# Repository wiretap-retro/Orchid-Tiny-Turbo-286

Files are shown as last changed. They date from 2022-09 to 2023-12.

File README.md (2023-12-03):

# Orchid Tiny Turbo 286
A clone of the Orchid Tiny Turbo 286 acclerator to upgrade an XT system. Based on schematics by Tube Time.

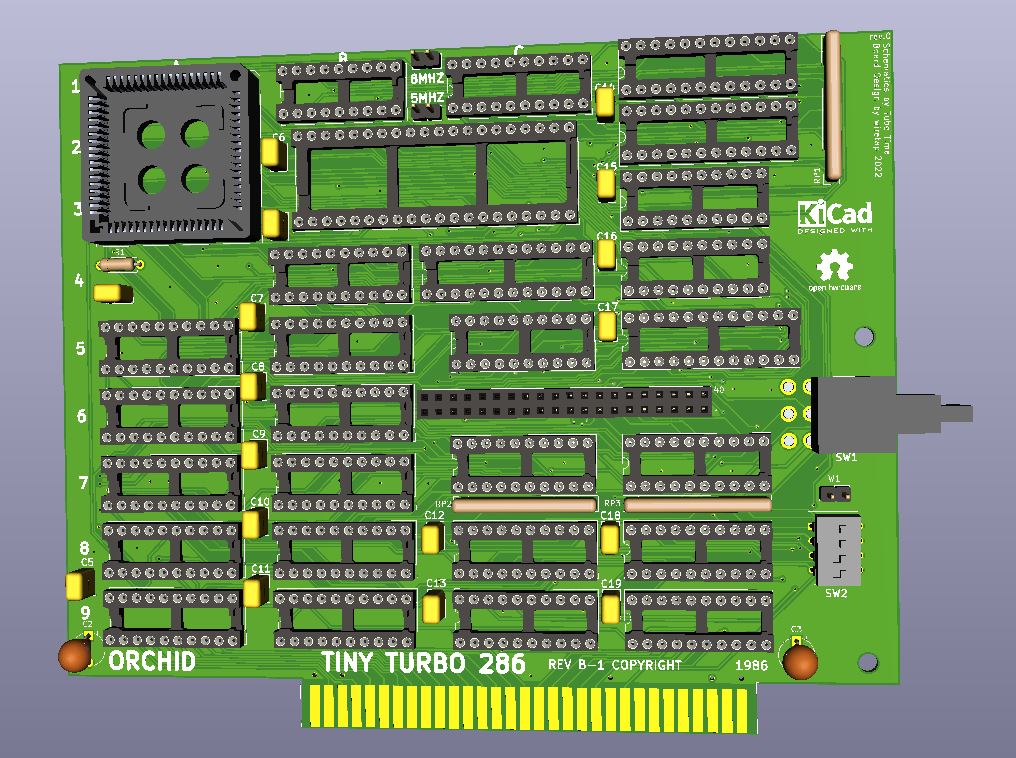
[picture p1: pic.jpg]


## Info / Warning
Build at your own risk This design is unconfirmed. PAL dumps have been added, courtesy of tomatolicious on the Retro Dreams and Techy Things Discord group. I do not have the original board, so this is a rough layout, not exactly the same size since it uses socketed footprints. However, it does abide by the ISA standard height (121.92mm) and uses a readily available slot cover that would need to be drilled for the switch to fit through. Board may require some more work -- this is considered a non-functional alpha release.
\
\
Built per the schematics from Tube Time's github found here: https://github.com/schlae/tiny-turbo-286

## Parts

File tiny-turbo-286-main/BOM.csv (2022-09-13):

Reference | Quantity | Value | Footprint | Datasheet
C1 | 1 | 0.1? | SamacSys_Parts:C320C104J3G5TA | ~
C3 C2 | 2 | 33uF 10V Tant | Capacitor_THT:CP_Radial_Tantal_D6.0mm_P5.00mm | ~
C4 C6 C8 C10 C12 C14 C16 C18 C5 C7 C9 C11 C13 C15 C17 C19 | 16 | 0.1uF | SamacSys_Parts:C320C104J3G5TA | ~
J1 | 1 | 8088_Max_Mode | Connector_PinSocket_2.54mm:PinSocket_2x20_P2.54mm_Vertical | http://datasheets.chipdb.org/Intel/x86/808x/datashts/8088/231456-006.pdf
J2 | 1 | Bus_ISA_8bit | SamacSys_Parts:BUS_XT | https://en.wikipedia.org/wiki/Industry_Standard_Architecture
R1 | 1 | 910 | Resistor_THT:R_Axial_DIN0207_L6.3mm_D2.5mm_P7.62mm_Horizontal | ~
RP2 RP3 RP1 | 3 | 4.7K | Resistor_THT:R_Array_SIP10 | http://www.vishay.com/docs/31509/csc.pdf
SW1 | 1 | TURBO | SamacSys_Parts:A201MD9AQ04
SW2 | 1 | SW_DIP_x04 | SamacSys_Parts:DIP810W60P254L1209H480Q8N | ~
UA2 | 1 | 80286_PLCC | Package_LCC:PLCC-68_THT-Socket
UA5 UA6 UB5 UB6 UB7 UB8 | 6 | IMS1423 | Package_DIP:DIP-20_W7.62mm_Socket
UA8 UA7 UD7 UD4 | 4 | 74ALS373 | Package_DIP:DIP-20_W7.62mm_Socket | http://www.ti.com/lit/gpn/sn74LS373
UA9 | 1 | 74LS541 | Package_DIP:DIP-20_W7.62mm_Socket | http://www.ti.com/lit/gpn/sn74LS541
UB1 | 1 | SAB82284 | Package_DIP:DIP-18_W7.62mm_Socket
UB2 | 1 | 80287 | Package_DIP:DIP-40_W15.24mm_Socket
UB4 | 1 | 74LS245 | Package_DIP:DIP-20_W7.62mm_Socket | http://www.ti.com/lit/gpn/sn74LS245
UB9 UC7 UC8 UD9 | 4 | 74ALS541 | Package_DIP:DIP-20_W7.62mm_Socket | http://www.ti.com/lit/gpn/sn74LS541
UC1 | 1 | 74AS804 | Package_DIP:DIP-20_W7.62mm_Socket
UC4 | 1 | 74LS646 | Package_DIP:DIP-24_W7.62mm_Socket
UC5 UD8 | 2 | PAL16L8 | Package_DIP:DIP-20_W7.62mm_Socket
UC9 | 1 | 74F521 | Package_DIP:DIP-20_W7.62mm_Socket | http://www.ti.com/lit/gpn/sn74LS688
UD1 | 1 | PAL20R6 | Package_DIP:DIP-24_W7.62mm_Socket
UD3 | 1 | PAL16R8 | Package_DIP:DIP-20_W7.62mm_Socket
UD5 UD2 | 2 | PAL20R4 | Package_DIP:DIP-24_W7.62mm_Socket
W1 | 1 | Jumper | Connector_PinHeader_2.54mm:PinHeader_1x02_P2.54mm_Vertical | ~
W2 | 1 | 8MHZ | Connector_PinHeader_2.54mm:PinHeader_1x02_P2.54mm_Vertical | ~
W3 | 1 | 5MHZ | Connector_PinHeader_2.54mm:PinHeader_1x02_P2.54mm_Vertical | ~

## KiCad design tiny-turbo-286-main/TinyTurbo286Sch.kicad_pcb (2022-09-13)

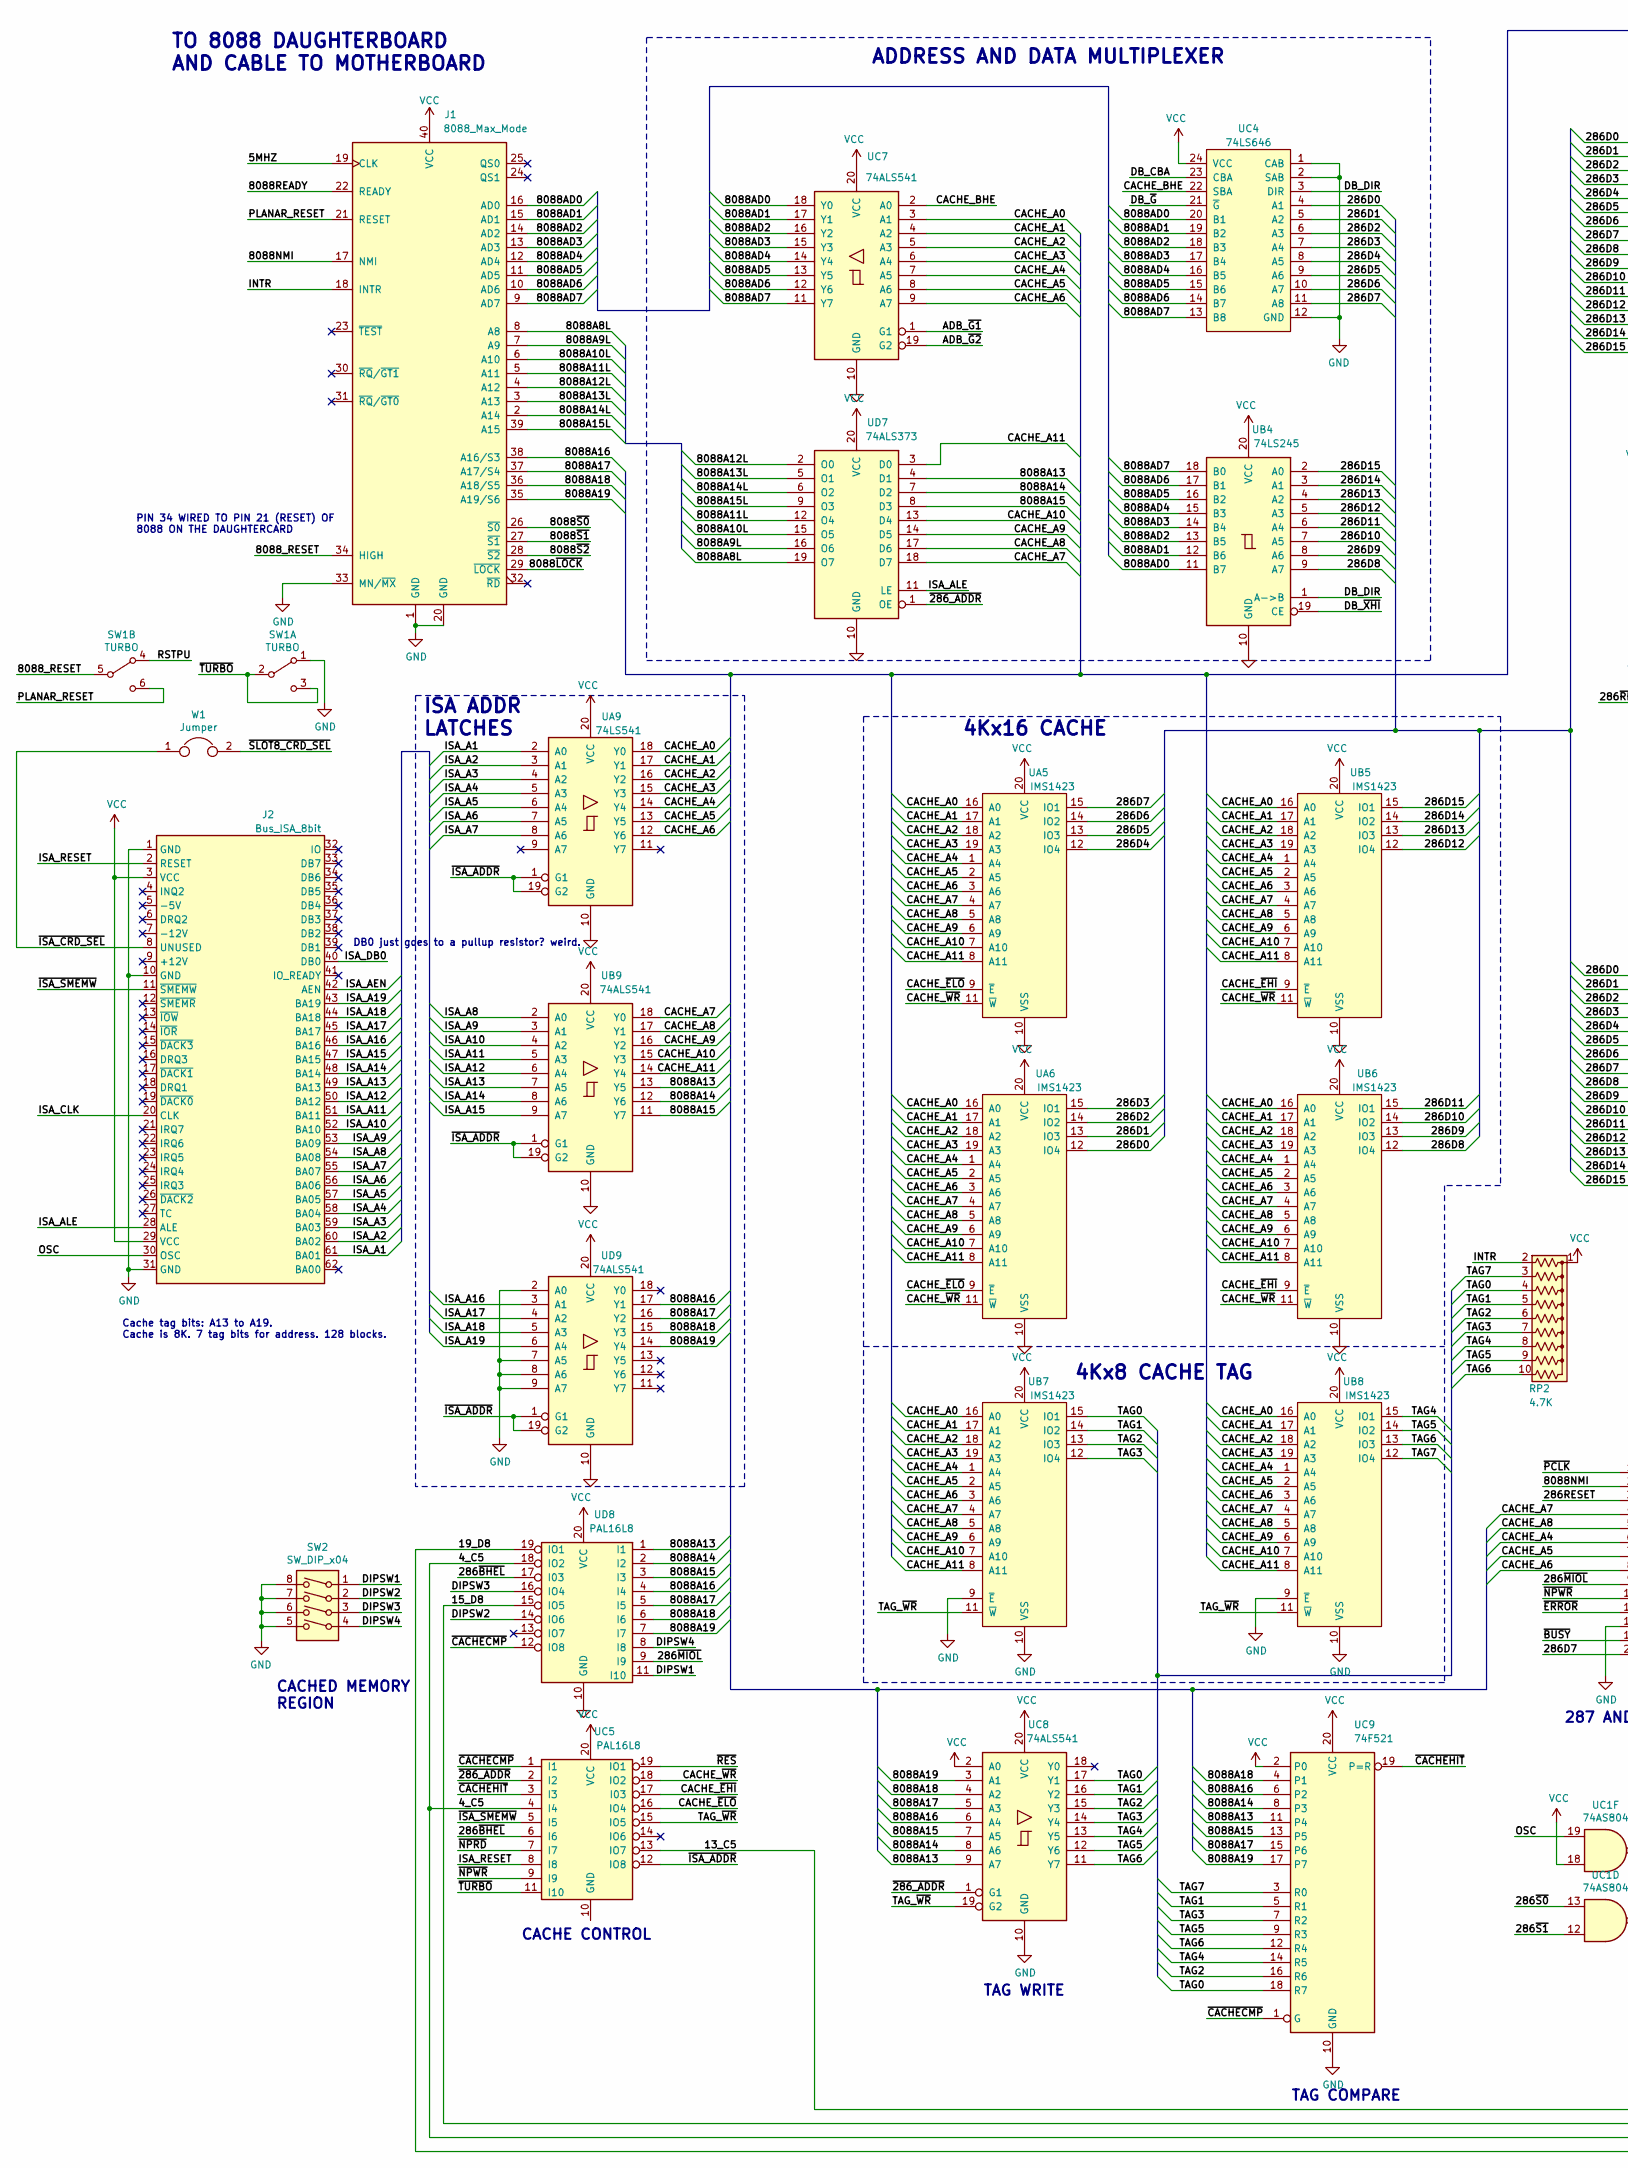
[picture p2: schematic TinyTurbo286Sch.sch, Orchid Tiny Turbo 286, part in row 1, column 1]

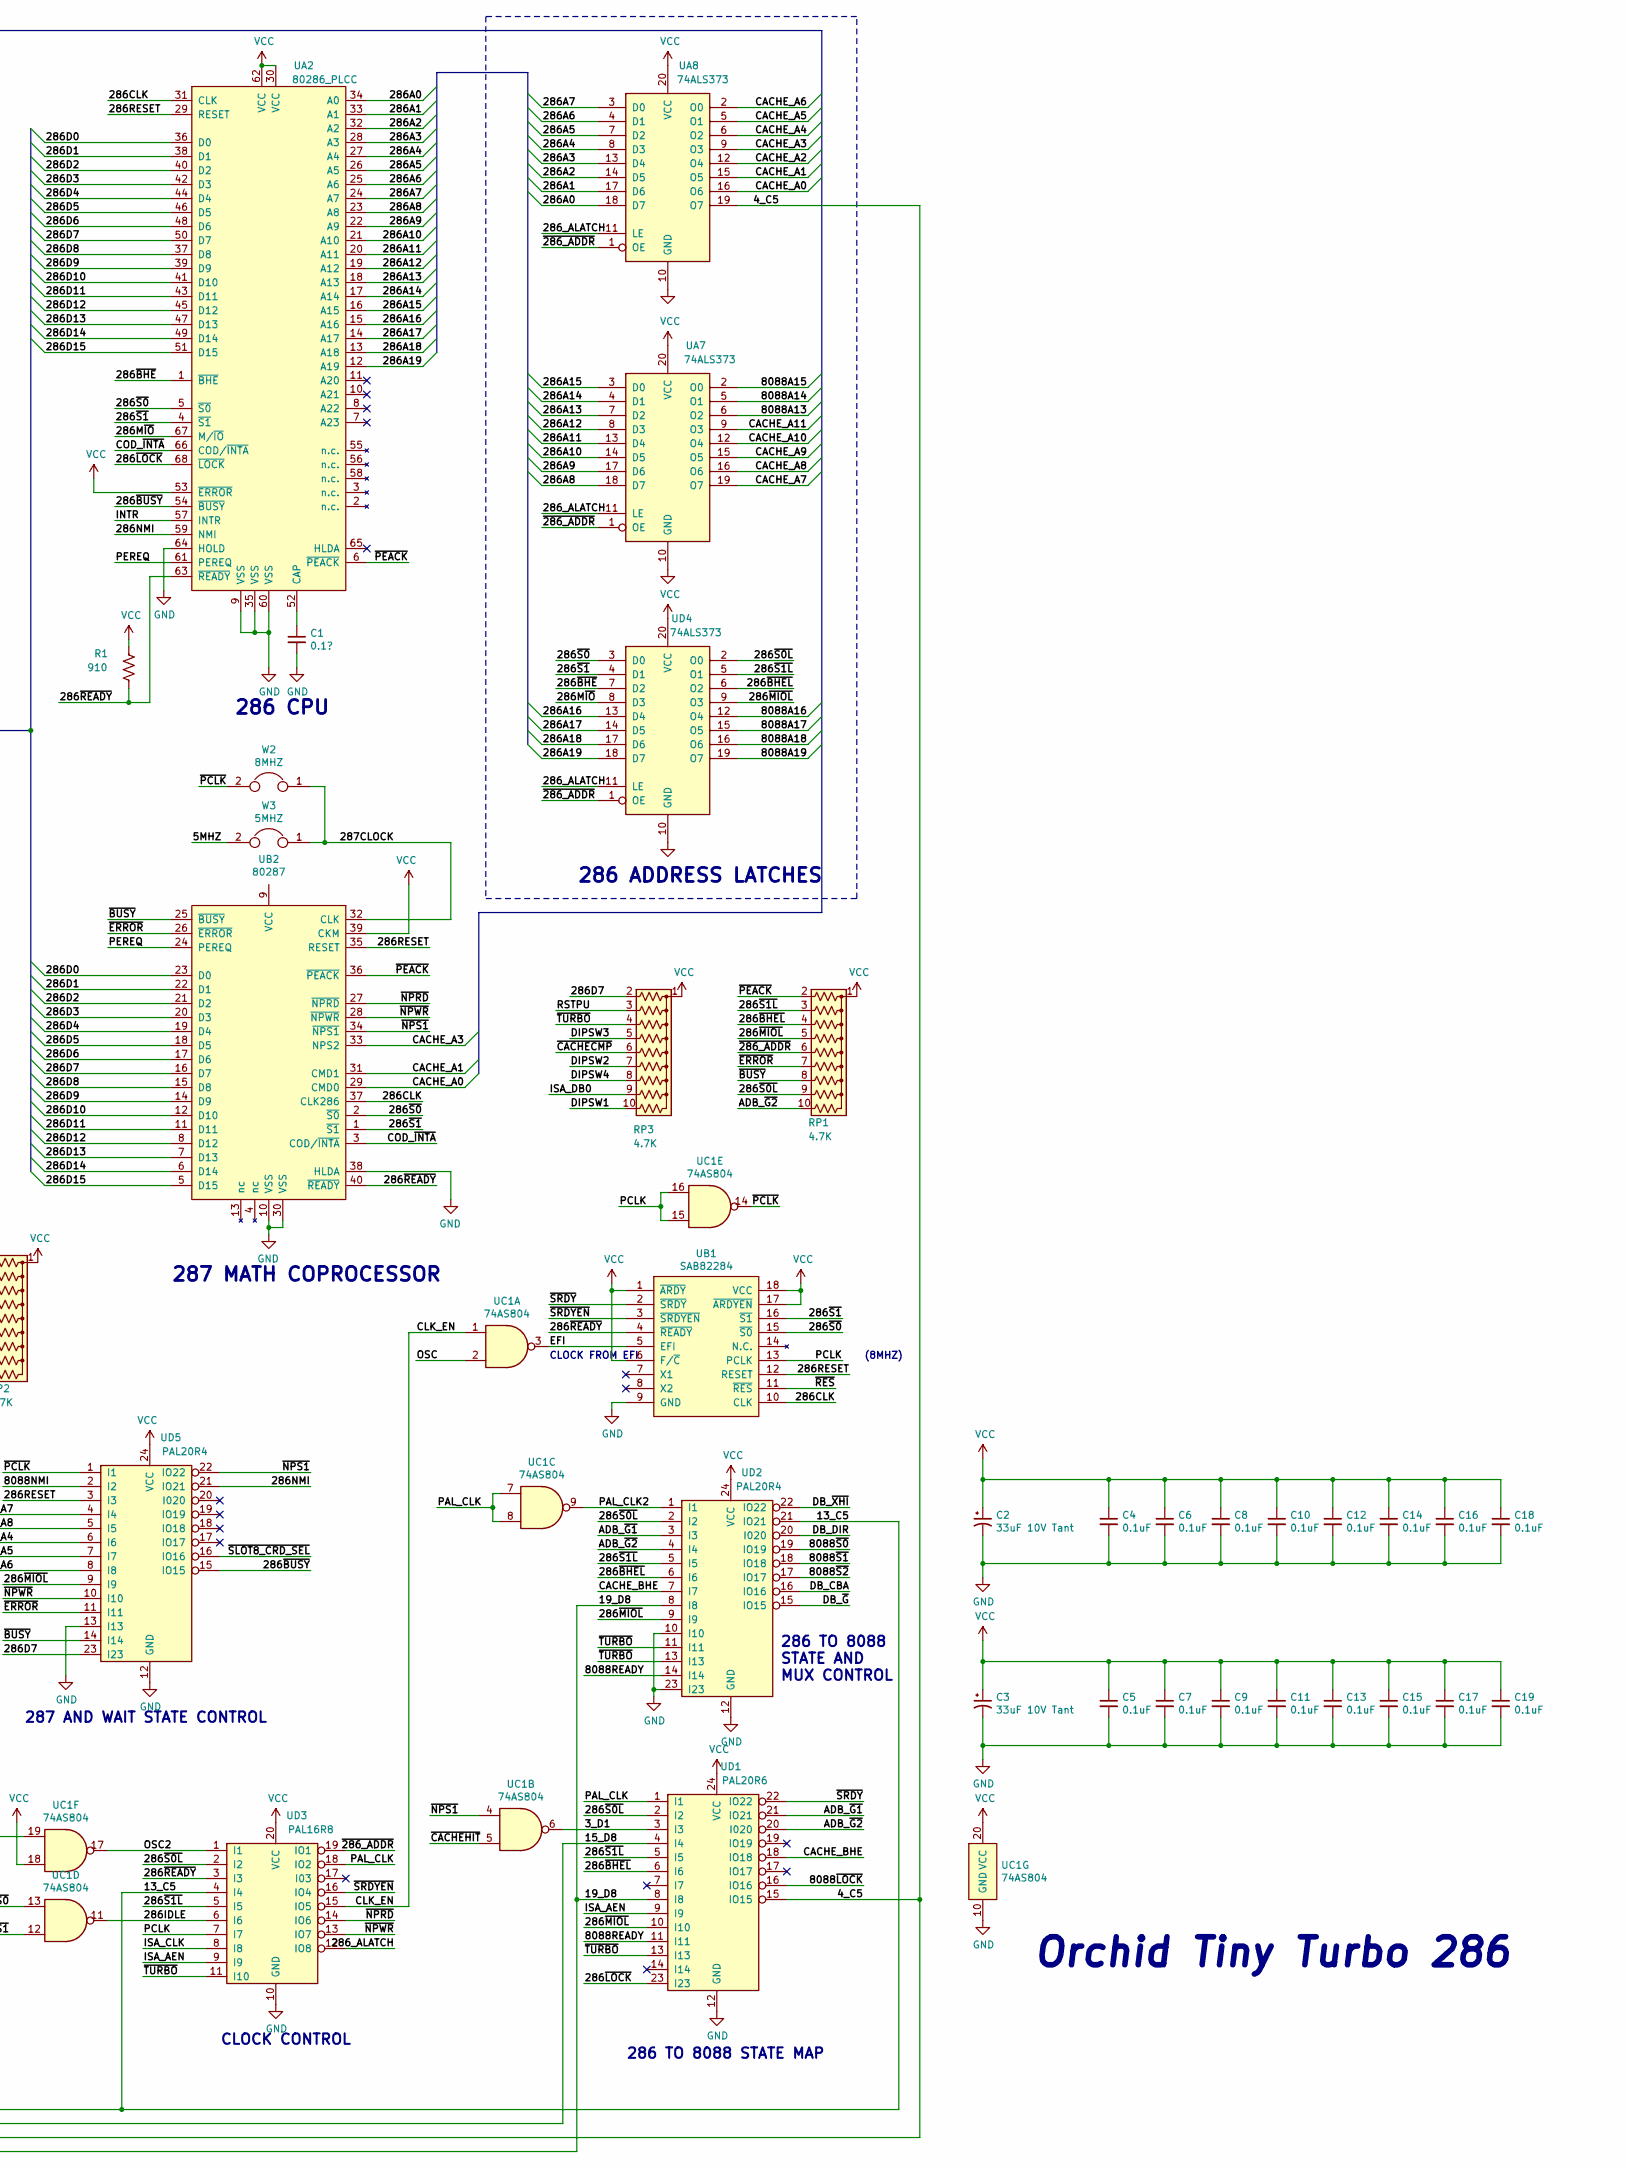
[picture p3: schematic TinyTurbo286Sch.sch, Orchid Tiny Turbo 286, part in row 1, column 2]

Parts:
C1: 0.1?; C320C104J3G5TA
C2, C3: 33uF 10V Tant; CP_Radial_Tantal_D6.0mm_P5.00mm
C4, C5, C6, C7, C8, C9, C10, C11, C12, C13, C14, C15, C16, C17, C18, C19: 0.1uF; C320C104J3G5TA
J1: 8088_Max_Mode; PinSocket_2x20_P2.54mm_Vertical
J2: Bus_ISA_8bit; BUS_XT
R1: 910; R_Axial_DIN0207_L6.3mm_D2.5mm_P7.62mm_Horizontal
RP1, RP2, RP3: 4.7K; R_Array_SIP10
SW1: TURBO; A201MD9AQ04
SW2: SW_DIP_x04; DIP810W60P254L1209H480Q8N
UA2: 80286_PLCC; PLCC-68_THT-Socket
UA5, UA6: IMS1423; DIP-20_W7.62mm_Socket
UA7, UA8: 74ALS373; DIP-20_W7.62mm_Socket
UA9: 74LS541; DIP-20_W7.62mm_Socket
UB1: SAB82284; DIP-18_W7.62mm_Socket
UB2: 80287; DIP-40_W15.24mm_Socket
UB4: 74LS245; DIP-20_W7.62mm_Socket
UB5, UB6, UB7, UB8: IMS1423; DIP-20_W7.62mm_Socket
UB9: 74ALS541; DIP-20_W7.62mm_Socket
UC1: 74AS804; DIP-20_W7.62mm_Socket
UC4: 74LS646; DIP-24_W7.62mm_Socket
UC5: PAL16L8; DIP-20_W7.62mm_Socket
UC7, UC8: 74ALS541; DIP-20_W7.62mm_Socket
UC9: 74F521; DIP-20_W7.62mm_Socket
UD1: PAL20R6; DIP-24_W7.62mm_Socket
UD2, UD5: PAL20R4; DIP-24_W7.62mm_Socket
UD3: PAL16R8; DIP-20_W7.62mm_Socket
UD4, UD7: 74ALS373; DIP-20_W7.62mm_Socket
UD8: PAL16L8; DIP-20_W7.62mm_Socket
UD9: 74ALS541; DIP-20_W7.62mm_Socket
W1: Jumper; PinHeader_1x02_P2.54mm_Vertical
W2: 8MHZ; PinHeader_1x02_P2.54mm_Vertical
W3: 5MHZ; PinHeader_1x02_P2.54mm_Vertical

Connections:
/3_D1: UC1.6, UD1.3 (I3)
/4_C5: UA8.19 (O7), UC5.4 (I4), UD1.15 (IO15), UD8.18 (IO2)
/5MHZ: J1.19 (CLK), W3.2
/13_C5: UC5.13 (IO7), UD2.21 (IO21), UD3.4 (I4)
/15_D8: UD1.4 (I4), UD8.15 (IO5)
/19_D8: UD1.8 (I8), UD2.8 (I8), UD8.19 (IO1)
/286A0: UA2.34 (A0), UA8.18 (D7)
/286A1: UA2.33 (A1), UA8.17 (D6)
/286A2: UA2.32 (A2), UA8.14 (D5)
/286A3: UA2.28 (A3), UA8.13 (D4)
/286A4: UA2.27 (A4), UA8.8 (D3)
/286A5: UA2.26 (A5), UA8.7 (D2)
/286A6: UA2.25 (A6), UA8.4 (D1)
/286A7: UA2.24 (A7), UA8.3 (D0)
/286A8: UA2.23 (A8), UA7.18 (D7)
/286A9: UA2.22 (A9), UA7.17 (D6)
/286A10: UA2.21 (A10), UA7.14 (D5)
/286A11: UA2.20 (A11), UA7.13 (D4)
/286A12: UA2.19 (A12), UA7.8 (D3)
/286A13: UA2.18 (A13), UA7.7 (D2)
/286A14: UA2.17 (A14), UA7.4 (D1)
/286A15: UA2.16 (A15), UA7.3 (D0)
/286A16: UA2.15 (A16), UD4.13 (D4)
/286A17: UA2.14 (A17), UD4.14 (D5)
/286A18: UA2.13 (A18), UD4.17 (D6)
/286A19: UA2.12 (A19), UD4.18 (D7)
/286CLK: UA2.31 (CLK), UB1.10 (CLK), UB2.37 (CLK286)
/286D0: UA2.36 (D0), UA6.12 (IO4), UB2.23 (D0), UC4.4 (A1)
/286D1: UA2.38 (D1), UA6.13 (IO3), UB2.22 (D1), UC4.5 (A2)
/286D2: UA2.40 (D2), UA6.14 (IO2), UB2.21 (D2), UC4.6 (A3)
/286D3: UA2.42 (D3), UA6.15 (IO1), UB2.20 (D3), UC4.7 (A4)
/286D4: UA2.44 (D4), UA5.12 (IO4), UB2.19 (D4), UC4.8 (A5)
/286D5: UA2.46 (D5), UA5.13 (IO3), UB2.18 (D5), UC4.9 (A6)
/286D6: UA2.48 (D6), UA5.14 (IO2), UB2.17 (D6), UC4.10 (A7)
/286D7: RP3.2 (R1), UA2.50 (D7), UA5.15 (IO1), UB2.16 (D7), UC4.11 (A8), UD5.23 (I23)
/286D8: UA2.37 (D8), UB2.15 (D8), UB4.9 (A7), UB6.12 (IO4)
/286D9: UA2.39 (D9), UB2.14 (D9), UB4.8 (A6), UB6.13 (IO3)
/286D10: UA2.41 (D10), UB2.12 (D10), UB4.7 (A5), UB6.14 (IO2)
/286D11: UA2.43 (D11), UB2.11 (D11), UB4.6 (A4), UB6.15 (IO1)
/286D12: UA2.45 (D12), UB2.8 (D12), UB4.5 (A3), UB5.12 (IO4)
/286D13: UA2.47 (D13), UB2.7 (D13), UB4.4 (A2), UB5.13 (IO3)
/286D14: UA2.49 (D14), UB2.6 (D14), UB4.3 (A1), UB5.14 (IO2)
/286D15: UA2.51 (D15), UB2.5 (D15), UB4.2 (A0), UB5.15 (IO1)
/286IDLE: UC1.11, UD3.6 (I6)
/286M~IO: UA2.67 (M/~IO), UD4.8 (D3)
/286NMI: UA2.59 (NMI), UD5.21 (IO21)
/286RESET: UA2.29 (RESET), UB1.12 (RESET), UB2.35 (RESET), UD5.3 (I3)
/286_ALATCH: UA7.11 (LE), UA8.11 (LE), UD3.12 (IO8), UD4.11 (LE)
/286~BHE: UA2.1 (~BHE), UD4.7 (D2)
/286~BHEL: RP1.4 (R3), UC5.6 (I6), UD1.6 (I6), UD2.6 (I6), UD4.6 (O2), UD8.17 (I03)
/286~BUSY: UA2.54 (~BUSY), UD5.15 (IO15)
/286~LOCK: UA2.68 (~LOCK), UD1.23 (I23)
/286~MIOL: RP1.5 (R4), UD1.10 (I10), UD2.9 (I9), UD4.9 (O3), UD5.9 (I9), UD8.9 (I9)
/286~READY: R1.2, UA2.63 (~READY), UB1.4 (~READY), UB2.40 (~READY), UD3.3 (I3)
/286~S0: UA2.5 (~S0), UB1.15 (~S0), UB2.2 (~S0), UC1.13, UD4.3 (D0)
/286~S0L: RP1.9 (R8), UD1.2 (I2), UD2.2 (I2), UD3.2 (I2), UD4.2 (O0)
/286~S1: UA2.4 (~S1), UB1.16 (~S1), UB2.1 (~S1), UC1.12, UD4.4 (D1)
/286~S1L: RP1.3 (R2), UD1.5 (I5), UD2.5 (I5), UD3.5 (I5), UD4.5 (O1)
/287CLOCK: UB2.32 (CLK), W2.1, W3.1
/8088A8L: J1.8 (A8), UD7.19 (O7)
/8088A9L: J1.7 (A9), UD7.16 (O6)
/8088A10L: J1.6 (A10), UD7.15 (O5)
/8088A11L: J1.5 (A11), UD7.12 (O4)
/8088A12L: J1.4 (A12), UD7.2 (O0)
/8088A13: UA7.6 (O2), UB9.13 (Y5), UC8.9 (A7), UC9.11 (P4), UD7.4 (D1), UD8.1 (I1)
/8088A13L: J1.3 (A13), UD7.5 (O1)
/8088A14: UA7.5 (O1), UB9.12 (Y6), UC8.8 (A6), UC9.8 (P3), UD7.7 (D2), UD8.2 (I2)
/8088A14L: J1.2 (A14), UD7.6 (O2)
/8088A15: UA7.2 (O0), UB9.11 (Y7), UC8.7 (A5), UC9.13 (P5), UD7.8 (D3), UD8.3 (I3)
/8088A15L: J1.39 (A15), UD7.9 (O3)
/8088A16: J1.38 (A16/S3), UC8.6 (A4), UC9.6 (P2), UD4.12 (O4), UD8.4 (I4), UD9.17 (Y1)
/8088A17: J1.37 (A17/S4), UC8.5 (A3), UC9.15 (P6), UD4.15 (O5), UD8.5 (I5), UD9.16 (Y2)
/8088A18: J1.36 (A18/S5), UC8.4 (A2), UC9.4 (P1), UD4.16 (O6), UD8.6 (I6), UD9.15 (Y3)
/8088A19: J1.35 (A19/S6), UC8.3 (A1), UC9.17 (P7), UD4.19 (O7), UD8.7 (I7), UD9.14 (Y4)
/8088AD0: J1.16 (AD0), UB4.11 (B7), UC4.20 (B1), UC7.18 (Y0)
/8088AD1: J1.15 (AD1), UB4.12 (B6), UC4.19 (B2), UC7.17 (Y1)
/8088AD2: J1.14 (AD2), UB4.13 (B5), UC4.18 (B3), UC7.16 (Y2)
/8088AD3: J1.13 (AD3), UB4.14 (B4), UC4.17 (B4), UC7.15 (Y3)
/8088AD4: J1.12 (AD4), UB4.15 (B3), UC4.16 (B5), UC7.14 (Y4)
/8088AD5: J1.11 (AD5), UB4.16 (B2), UC4.15 (B6), UC7.13 (Y5)
/8088AD6: J1.10 (AD6), UB4.17 (B1), UC4.14 (B7), UC7.12 (Y6)
/8088AD7: J1.9 (AD7), UB4.18 (B0), UC4.13 (B8), UC7.11 (Y7)
/8088NMI: J1.17 (NMI), UD5.2 (I2)
/8088READY: J1.22 (READY), UD1.11 (I11), UD2.14 (I14)
/8088_RESET: J1.34 (HIGH), SW1.5 (B)
/8088~LOCK: J1.29 (~LOCK~), UD1.16 (IO16)
/8088~S0: J1.26 (~S0~), UD2.19 (IO19)
/8088~S1: J1.27 (~S1~), UD2.18 (IO18)
/8088~S2: J1.28 (~S2~), UD2.17 (IO17)
/ADB_~G1: UC7.1 (G1), UD1.21 (IO21), UD2.3 (I3)
/ADB_~G2: RP1.10 (R9), UC7.19 (G2), UD1.20 (I020), UD2.4 (I4)
/CACHE_A0: UA5.16 (A0), UA6.16 (A0), UA8.16 (O6), UA9.18 (Y0), UB2.29 (CMD0), UB5.16 (A0), UB6.16 (A0), UB7.16 (A0), UB8.16 (A0), UC7.3 (A1)
/CACHE_A1: UA5.17 (A1), UA6.17 (A1), UA8.15 (O5), UA9.17 (Y1), UB2.31 (CMD1), UB5.17 (A1), UB6.17 (A1), UB7.17 (A1), UB8.17 (A1), UC7.4 (A2)
/CACHE_A2: UA5.18 (A2), UA6.18 (A2), UA8.12 (O4), UA9.16 (Y2), UB5.18 (A2), UB6.18 (A2), UB7.18 (A2), UB8.18 (A2), UC7.5 (A3)
/CACHE_A3: UA5.19 (A3), UA6.19 (A3), UA8.9 (O3), UA9.15 (Y3), UB2.33 (NPS2), UB5.19 (A3), UB6.19 (A3), UB7.19 (A3), UB8.19 (A3), UC7.6 (A4)
/CACHE_A4: UA5.1 (A4), UA6.1 (A4), UA8.6 (O2), UA9.14 (Y4), UB5.1 (A4), UB6.1 (A4), UB7.1 (A4), UB8.1 (A4), UC7.7 (A5), UD5.6 (I6)
/CACHE_A5: UA5.2 (A5), UA6.2 (A5), UA8.5 (O1), UA9.13 (Y5), UB5.2 (A5), UB6.2 (A5), UB7.2 (A5), UB8.2 (A5), UC7.8 (A6), UD5.7 (I7)
/CACHE_A6: UA5.3 (A6), UA6.3 (A6), UA8.2 (O0), UA9.12 (Y6), UB5.3 (A6), UB6.3 (A6), UB7.3 (A6), UB8.3 (A6), UC7.9 (A7), UD5.8 (I8)
/CACHE_A7: UA5.4 (A7), UA6.4 (A7), UA7.19 (O7), UB5.4 (A7), UB6.4 (A7), UB7.4 (A7), UB8.4 (A7), UB9.18 (Y0), UD5.4 (I4), UD7.18 (D7)
/CACHE_A8: UA5.5 (A8), UA6.5 (A8), UA7.16 (O6), UB5.5 (A8), UB6.5 (A8), UB7.5 (A8), UB8.5 (A8), UB9.17 (Y1), UD5.5 (I5), UD7.17 (D6)
/CACHE_A9: UA5.6 (A9), UA6.6 (A9), UA7.15 (O5), UB5.6 (A9), UB6.6 (A9), UB7.6 (A9), UB8.6 (A9), UB9.16 (Y2), UD7.14 (D5)
/CACHE_A10: UA5.7 (A10), UA6.7 (A10), UA7.12 (O4), UB5.7 (A10), UB6.7 (A10), UB7.7 (A10), UB8.7 (A10), UB9.15 (Y3), UD7.13 (D4)
/CACHE_A11: UA5.8 (A11), UA6.8 (A11), UA7.9 (O3), UB5.8 (A11), UB6.8 (A11), UB7.8 (A11), UB8.8 (A11), UB9.14 (Y4), UD7.3 (D0)
/CACHE_BHE: UC4.22 (SBA), UC7.2 (A0), UD1.18 (IO18), UD2.7 (I7)
/CACHE_~EHI: UB5.9 (~E), UB6.9 (~E), UC5.17 (I03)
/CACHE_~ELO: UA5.9 (~E), UA6.9 (~E), UC5.16 (IO4)
/CACHE_~WR: UA5.11 (~W), UA6.11 (~W), UB5.11 (~W), UB6.11 (~W), UC5.18 (IO2)
/CLK_EN: UC1.1, UD3.15 (IO5)
/COD_~INTA: UA2.66 (COD/~INTA), UB2.3 (COD/~INTA)
/DB_CBA: UC4.23 (CBA), UD2.16 (IO16)
/DB_DIR: UB4.1 (A->B), UC4.3 (DIR), UD2.20 (I020)
/DB_~G: UC4.21 (~G), UD2.15 (IO15)
/DB_~XHI: UB4.19 (CE), UD2.22 (IO22)
/DIPSW1: RP3.10 (R9), SW2.1, UD8.11 (I10)
/DIPSW2: RP3.7 (R6), SW2.2, UD8.14 (IO6)
/DIPSW3: RP3.5 (R4), SW2.3, UD8.16 (IO4)
/DIPSW4: RP3.8 (R7), SW2.4, UD8.8 (I8)
/EFI: UB1.5 (EFI), UC1.3
/INTR: J1.18 (INTR), RP2.2 (R1), UA2.57 (INTR)
/ISA_A1: J2.61 (BA01), UA9.2 (A0)
/ISA_A2: J2.60 (BA02), UA9.3 (A1)
/ISA_A3: J2.59 (BA03), UA9.4 (A2)
/ISA_A4: J2.58 (BA04), UA9.5 (A3)
/ISA_A5: J2.57 (BA05), UA9.6 (A4)
/ISA_A6: J2.56 (BA06), UA9.7 (A5)
/ISA_A7: J2.55 (BA07), UA9.8 (A6)
/ISA_A8: J2.54 (BA08), UB9.2 (A0)
/ISA_A9: J2.53 (BA09), UB9.3 (A1)
/ISA_A10: J2.52 (BA10), UB9.4 (A2)
/ISA_A11: J2.51 (BA11), UB9.5 (A3)
/ISA_A12: J2.50 (BA12), UB9.6 (A4)
/ISA_A13: J2.49 (BA13), UB9.7 (A5)
/ISA_A14: J2.48 (BA14), UB9.8 (A6)
/ISA_A15: J2.47 (BA15), UB9.9 (A7)
/ISA_A16: J2.46 (BA16), UD9.3 (A1)
/ISA_A17: J2.45 (BA17), UD9.4 (A2)
/ISA_A18: J2.44 (BA18), UD9.5 (A3)
/ISA_A19: J2.43 (BA19), UD9.6 (A4)
/ISA_AEN: J2.42 (AEN), UD1.9 (I9), UD3.9 (I9)
/ISA_ALE: J2.28 (ALE), UD7.11 (LE)
/ISA_CLK: J2.20 (CLK), UD3.8 (I8)
/ISA_DB0: J2.40 (DB0), RP3.9 (R8)
/ISA_RESET: J2.2 (RESET), UC5.8 (I8)
/OSC: J2.30 (OSC), UC1.2, UC1.19
/OSC2: UC1.17, UD3.1 (I1)
/PAL_CLK: UC1.7, UC1.8, UD1.1 (I1), UD3.18 (IO2)
/PAL_CLK2: UC1.9, UD2.1 (I1)
/PCLK: UB1.13 (PCLK), UC1.15, UC1.16, UD3.7 (I7)
/PEREQ: UA2.61 (PEREQ), UB2.24 (PEREQ)
/PLANAR_RESET: J1.21 (RESET), SW1.6 (C)
/RSTPU: RP3.3 (R2), SW1.4 (A)
/TAG0: RP2.4 (R3), UB7.15 (IO1), UC8.17 (Y1), UC9.18 (R7)
/TAG1: RP2.5 (R4), UB7.14 (IO2), UC8.16 (Y2), UC9.5 (R1)
/TAG2: RP2.6 (R5), UB7.13 (IO3), UC8.15 (Y3), UC9.16 (R6)
/TAG3: RP2.7 (R6), UB7.12 (IO4), UC8.14 (Y4), UC9.7 (R2)
/TAG4: RP2.8 (R7), UB8.15 (IO1), UC8.13 (Y5), UC9.14 (R5)
/TAG5: RP2.9 (R8), UB8.14 (IO2), UC8.12 (Y6), UC9.9 (R3)
/TAG6: RP2.10 (R9), UB8.13 (IO3), UC8.11 (Y7), UC9.12 (R4)
/TAG7: RP2.3 (R2), UB8.12 (IO4), UC9.3 (R0)
/TAG_~WR: UB7.11 (~W), UB8.11 (~W), UC5.15 (IO5), UC8.19 (G2)
/~286_ADDR: RP1.6 (R5), UA7.1 (OE), UA8.1 (OE), UC5.2 (I2), UC8.1 (G1), UD3.19 (IO1), UD4.1 (OE), UD7.1 (OE)
/~BUSY: RP1.8 (R7), UB2.25 (~BUSY), UD5.14 (I14)
/~CACHECMP: RP3.6 (R5), UC5.1 (I1), UC9.1 (G), UD8.12 (IO8)
/~CACHEHIT: UC1.5, UC5.3 (I3), UC9.19 (P=R)
/~ERROR: RP1.7 (R6), UB2.26 (~ERROR), UD5.11 (I11)
/~ISA_ADDR: UA9.1 (G1), UA9.19 (G2), UB9.1 (G1), UB9.19 (G2), UC5.12 (IO8), UD9.1 (G1), UD9.19 (G2)
/~ISA_CRD_SEL: J2.8 (UNUSED), W1.1
/~ISA_SMEMW: J2.11 (~SMEMW), UC5.5 (I5)
/~NPRD: UB2.27 (~NPRD), UC5.7 (I7), UD3.14 (IO6)
/~NPS1: UB2.34 (~NPS1), UC1.4, UD5.22 (IO22)
/~NPWR: UB2.28 (~NPWR), UC5.9 (I9), UD3.13 (IO7), UD5.10 (I10)
/~PCLK: UC1.14, UD5.1 (I1), W2.2
/~PEACK: RP1.2 (R1), UA2.6 (~PEACK), UB2.36 (~PEACK)
/~RES: UB1.11 (~RES), UC5.19 (IO1)
/~SLOT8_CRD_SEL: UD5.16 (IO16), W1.2
/~SRDY: UB1.2 (~SRDY), UD1.22 (IO22)
/~SRDYEN: UB1.3 (~SRDYEN), UD3.16 (IO4)
/~TURBO: RP3.4 (R3), SW1.2 (B), SW1.3 (C), UC5.11 (I10), UD1.13 (I13), UD2.11 (I11), UD2.13 (I13), UD3.11 (I10)
GND: C1.2, C2.2, C3.2, C4.2, C5.2, C6.2, C7.2, C8.2, C9.2, C10.2, C11.2, C12.2, C13.2, C14.2, C15.2, C16.2, C17.2, C18.2, C19.2, J1.1 (GND), J1.20 (GND), J1.33 (MN/~MX~), J2.1 (GND), J2.10 (GND), J2.31 (GND), SW1.1 (A), SW2.5, SW2.6, SW2.7, SW2.8, UA2.9 (VSS), UA2.35 (VSS), UA2.60 (VSS), UA2.64 (HOLD), UA5.10 (VSS), UA6.10 (VSS), UA7.10 (GND), UA8.10 (GND), UA9.10 (GND), UB1.9 (GND), UB2.10 (VSS), UB2.30 (VSS), UB2.38 (HLDA), UB4.10 (GND), UB5.10 (VSS), UB6.10 (VSS), UB7.9 (~E), UB7.10 (VSS), UB8.9 (~E), UB8.10 (VSS), UB9.10 (GND), UC1.10 (GND), UC4.1 (CAB), UC4.2 (SAB), UC4.12 (GND), UC7.10 (GND), UC8.10 (GND), UC9.10 (GND), UD1.12 (GND), UD2.10 (I10), UD2.12 (GND), UD2.23 (I23), UD3.10 (GND), UD4.10 (GND), UD5.12 (GND), UD5.13 (I13), UD7.10 (GND), UD8.10 (GND), UD9.2 (A0), UD9.7 (A5), UD9.8 (A6), UD9.9 (A7), UD9.10 (GND)
unnamed: C1.1, UA2.52 (CAP)
VCC: C2.1, C3.1, C4.1, C5.1, C6.1, C7.1, C8.1, C9.1, C10.1, C11.1, C12.1, C13.1, C14.1, C15.1, C16.1, C17.1, C18.1, C19.1, J1.40 (VCC), J2.3 (VCC), J2.29 (VCC), R1.1, RP1.1 (common), RP2.1 (common), RP3.1 (common), UA2.30 (VCC), UA2.53 (~ERROR), UA2.62 (VCC), UA5.20 (VCC), UA6.20 (VCC), UA7.20 (VCC), UA8.20 (VCC), UA9.20 (VCC), UB1.1 (~ARDY), UB1.6 (F/~C), UB1.17 (~ARDYEN), UB1.18 (VCC), UB2.39 (CKM), UB4.20 (VCC), UB5.20 (VCC), UB6.20 (VCC), UB7.20 (VCC), UB8.20 (VCC), UB9.20 (VCC), UC1.18, UC1.20 (VCC), UC4.24 (VCC), UC5.20 (VCC), UC7.20 (VCC), UC8.2 (A0), UC8.20 (VCC), UC9.2 (P0), UC9.20 (VCC), UD1.24 (VCC), UD2.24 (VCC), UD3.20 (VCC), UD4.20 (VCC), UD5.24 (VCC), UD7.20 (VCC), UD8.20 (VCC), UD9.20 (VCC)

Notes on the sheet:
Cache tag bits: A13 to A19. Cache is 8K. 7 tag bits for address. 128 blocks.
PIN 34 WIRED TO PIN 21 (RESET) OF 8088 ON THE DAUGHTERCARD
CLOCK FROM EFI
DB0 just goes to a pullup resistor? weird.
CACHE CONTROL
287 AND WAIT STATE CONTROL
CLOCK CONTROL
286 TO 8088 STATE AND MUX CONTROL
286 TO 8088 STATE MAP
CACHED MEMORY REGION
TAG WRITE
TAG COMPARE
287 MATH COPROCESSOR
286 CPU
286 ADDRESS LATCHES
(8MHZ)
4Kx8 CACHE TAG
4Kx16 CACHE
ADDRESS AND DATA MULTIPLEXER
ISA ADDR LATCHES
TO 8088 DAUGHTERBOARD AND CABLE TO MOTHERBOARD
Orchid Tiny Turbo 286

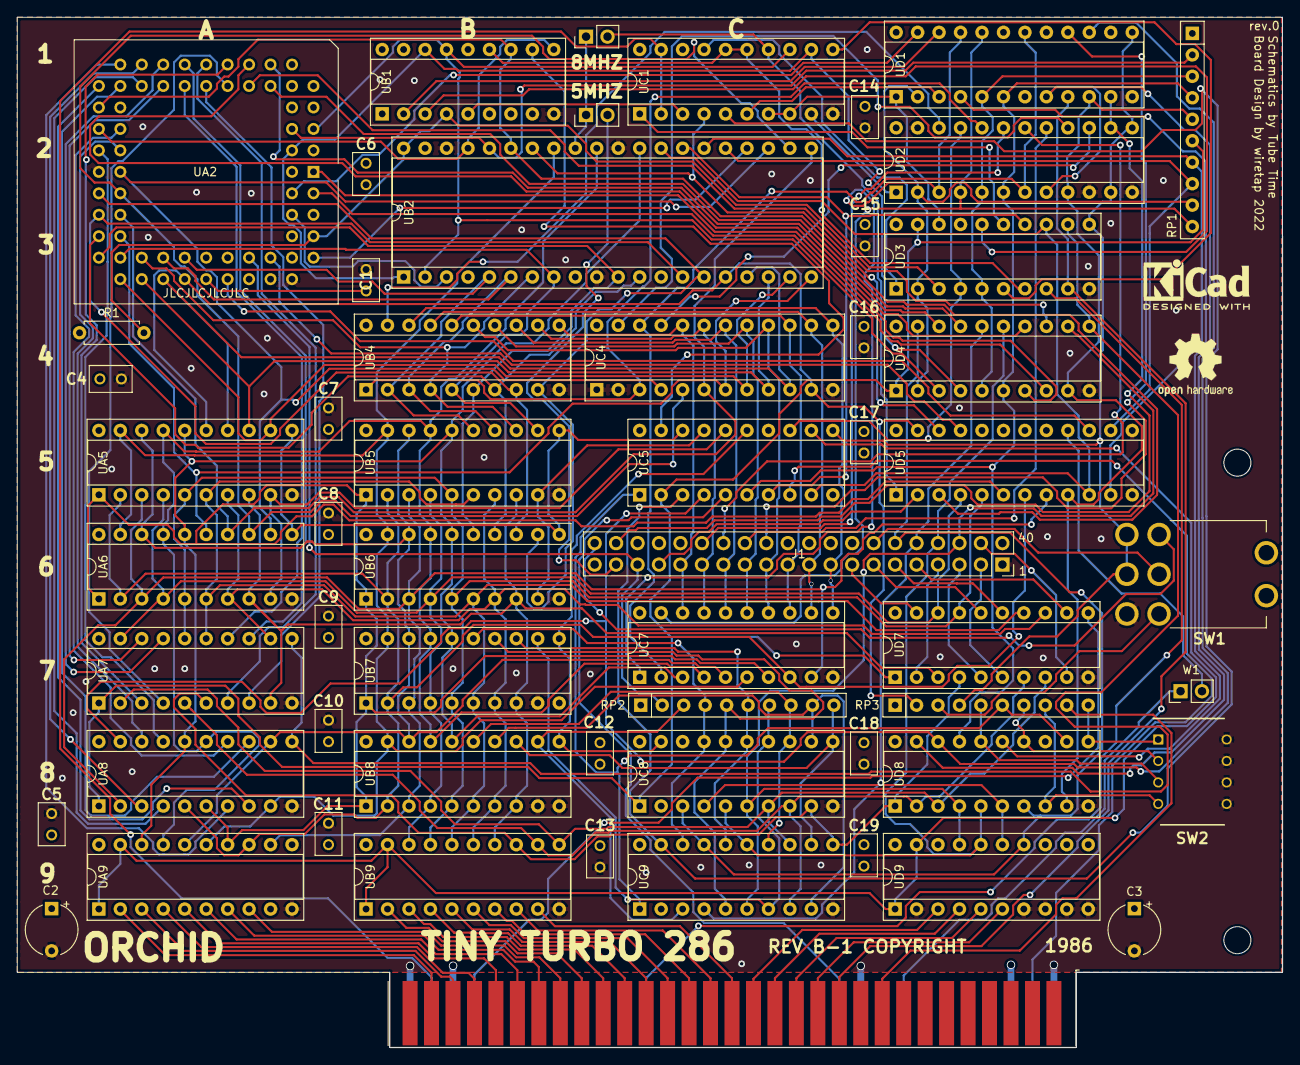
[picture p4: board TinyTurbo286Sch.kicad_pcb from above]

Board: 4 copper layers, 149.7 x 121.9 mm, 60 parts (0 on the bottom side), 181 nets.

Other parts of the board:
P6, P7: CONN_1; MountingHole_3.2mm_M3

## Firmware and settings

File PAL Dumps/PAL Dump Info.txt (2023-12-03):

PAL dumps are from user "tomatolicious" on the Retro Dreams and Techy Things Discord: https://discord.gg/VrhKdcQf

The dumps were generated using this tool: https://store.backbit.io/product/chip-tester/

-----------
UD1.bin
-----------
PAL20R6 / 8-10 inputs / 6-8 outputs
Inputs: 2 3 4 5 6 7 8 9 10 11 14 23 15
Outputs: x 16 17 18 19 20 21 22

-----------
UD2.bin
-----------
PAL20R6 / 8-10 inputs / 6-8 outputs
Inputs: 2 3 4 5 6 7 8 9 10 11 14 23
Outputs: 15 16 17 18 19 20 21 22

-----------
UD3.bin
-----------
PAL16R8 / 8 inputs / 8 outputs

-----------
UC5.bin
-----------
PAL16L8 / 9-15 inputs / 2-8 outputs
Inputs: 1 2 3 4 5 6 7 8 9 11 13
Outputs: 12 x 14 15 16 17 18 19

-----------
UD5.bin
-----------
PAL20R4 / 8-12 inputs / 4-8 outputs
Inputs: 2 3 4 5 6 7 8 9 10 11 14 23
Outputs: 15 16 17 18 19 20 21 22

-----------
UD8.bin
-----------
PAL16L8 / 9-15 inputs / 2-8 outputs
Inputs: 1 2 3 4 5 6 7 8 9 11 14 16 17 18
Outputs: 12 13 x 15 x x x 19

----------------------------------------------

GAL16V8  /  GAL20V8  /  GAL22V10 
Capable  of  saving  logic  equations  to  file.
●        PAL  16L8  /  16R4  /  16R6  /  16R8
Capable  of  saving  logic  equations  to  file,  and  interpreting  I/O  pins  as  either  input  or  output. 
Saves  data  to  file,  with  lowest  input  pin  #  being  the  least  significant  address,  and  each  output  pin 
representing  a  data  bit,  with  lowest  pin  #  being  the  least  significant  data  bit.  Outputs  configured 
as  inputs  will  ride  high.

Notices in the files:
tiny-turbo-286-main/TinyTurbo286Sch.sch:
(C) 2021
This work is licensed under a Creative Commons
